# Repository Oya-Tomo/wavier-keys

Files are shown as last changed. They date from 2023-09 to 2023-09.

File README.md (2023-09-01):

# Wavier Keys Firmware and Circuit

## tech

tech

## description

this repo contains the firmware program written in Rust with rp-2040 bsp and circuit file made with kicad.

test, test, ah... ah...
This message was written with Wavier Keys keyboard.

## author

Oya-Tomo

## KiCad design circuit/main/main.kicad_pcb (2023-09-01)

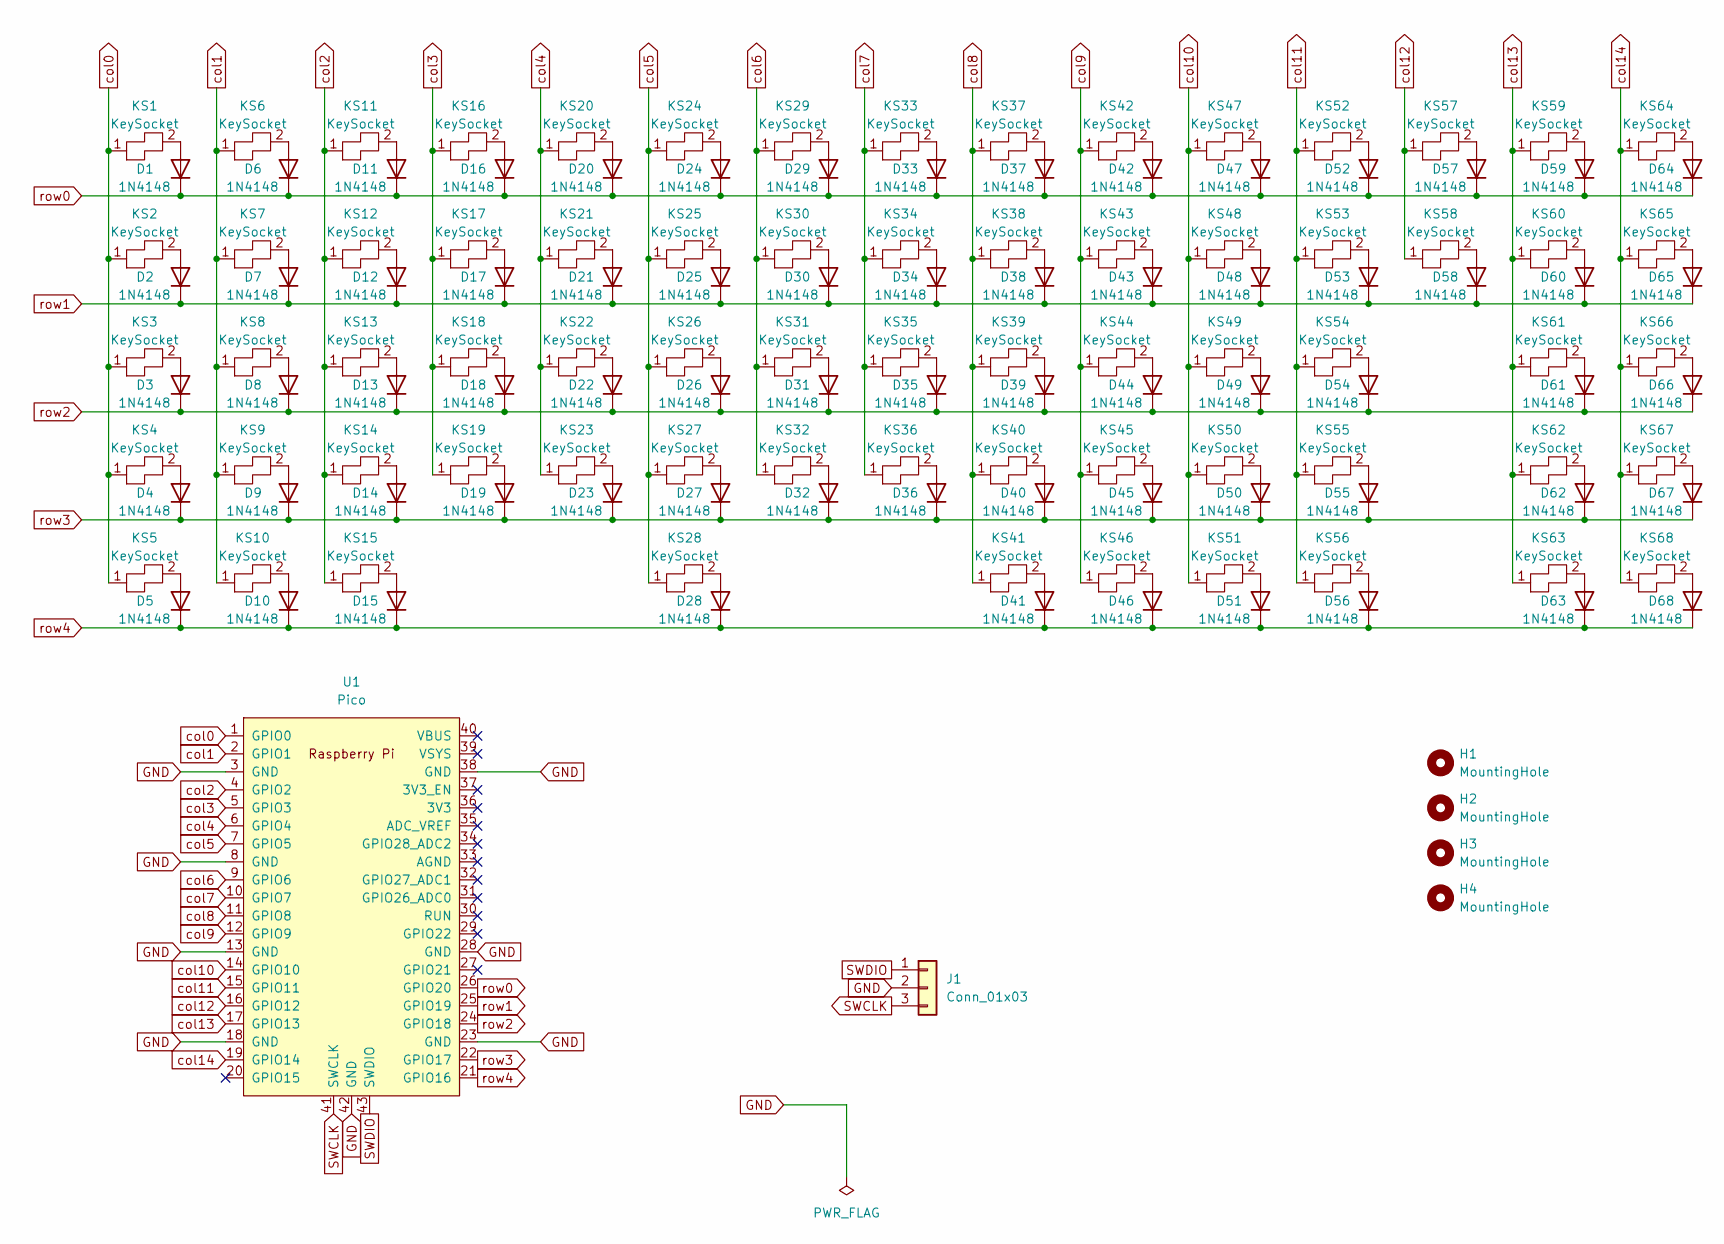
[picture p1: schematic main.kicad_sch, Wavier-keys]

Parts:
D1, D2, D3, D4, D5, D6, D7, D8, D9, D10, D11, D12, D13, D14, D15, D16, D17, D18, D19, D20, D21, D22, D23, D24, D25, D26, D27, D28, D29, D30, D31, D32, D33, D34, D35, D36, D37, D38, D39, D40, D41, D42, D43, D44, D45, D46, D47, D48, D49, D50, D51, D52, D53, D54, D55, D56, D57, D58, D59, D60, D61, D62, D63, D64, D65, D66, D67, D68: 1N4148; D_DO-35_SOD27_P7.62mm_Horizontal
H1, H2, H3, H4: MountingHole; MountingHole_2.5mm
J1: Conn_01x03; PinHeader_1x03_P2.54mm_Horizontal
KS1, KS6, KS7, KS8, KS9, KS11, KS12, KS13, KS14, KS16, KS17, KS18, KS19, KS20, KS21, KS22, KS23, KS24, KS25, KS26, KS27, KS29, KS30, KS31, KS32, KS33, KS34, KS35, KS36, KS37, KS38, KS39, KS40, KS41, KS42, KS43, KS44, KS45, KS46, KS47, KS48, KS49, KS50, KS51, KS52, KS53, KS54, KS56, KS57, KS58, KS59, KS62, KS63, KS65, KS66, KS67, KS68: KeySocket; SW_Hotswap_Kailh_MX_1.00u
KS2, KS60: KeySocket; SW_Hotswap_Kailh_MX_1.50u
KS3, KS55: KeySocket; SW_Hotswap_Kailh_MX_1.75u
KS4, KS61: KeySocket; SW_Hotswap_Kailh_MX_2.25u
KS5, KS10, KS15: KeySocket; SW_Hotswap_Kailh_MX_1.25u
KS28: KeySocket; SW_Hotswap_Kailh_MX_6.25u
KS64: KeySocket; SW_Hotswap_Kailh_MX_2.00u
U1: Pico; RPi_Pico_SMD_TH

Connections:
GND: J1.2, U1.3 (GND), U1.8 (GND), U1.13 (GND), U1.18 (GND), U1.23 (GND), U1.28 (GND), U1.38 (GND), U1.42 (GND)
unnamed: D1.2 (A), KS1.2
unnamed: D2.2 (A), KS2.2
unnamed: D3.2 (A), KS3.2
unnamed: D4.2 (A), KS4.2
unnamed: D5.2 (A), KS5.2
unnamed: D6.2 (A), KS6.2
unnamed: D7.2 (A), KS7.2
unnamed: D8.2 (A), KS8.2
unnamed: D9.2 (A), KS9.2
unnamed: D10.2 (A), KS10.2
unnamed: D11.2 (A), KS11.2
unnamed: D12.2 (A), KS12.2
unnamed: D13.2 (A), KS13.2
unnamed: D14.2 (A), KS14.2
unnamed: D15.2 (A), KS15.2
unnamed: D16.2 (A), KS16.2
unnamed: D17.2 (A), KS17.2
unnamed: D18.2 (A), KS18.2
unnamed: D19.2 (A), KS19.2
unnamed: D20.2 (A), KS20.2
unnamed: D21.2 (A), KS21.2
unnamed: D22.2 (A), KS22.2
unnamed: D23.2 (A), KS23.2
unnamed: D24.2 (A), KS24.2
unnamed: D25.2 (A), KS25.2
unnamed: D26.2 (A), KS26.2
unnamed: D27.2 (A), KS27.2
unnamed: D28.2 (A), KS28.2
unnamed: D29.2 (A), KS29.2
unnamed: D30.2 (A), KS30.2
unnamed: D31.2 (A), KS31.2
unnamed: D32.2 (A), KS32.2
unnamed: D33.2 (A), KS33.2
unnamed: D34.2 (A), KS34.2
unnamed: D35.2 (A), KS35.2
unnamed: D36.2 (A), KS36.2
unnamed: D37.2 (A), KS37.2
unnamed: D38.2 (A), KS38.2
unnamed: D39.2 (A), KS39.2
unnamed 40: D40.2 (A), KS40.2; also elsewhere on the board
unnamed: D41.2 (A), KS41.2
unnamed 42: D42.2 (A), KS42.2; also elsewhere on the board
unnamed: D43.2 (A), KS43.2
unnamed: D44.2 (A), KS44.2
unnamed: D45.2 (A), KS45.2
unnamed: D46.2 (A), KS46.2
unnamed: D47.2 (A), KS47.2
unnamed: D48.2 (A), KS48.2
unnamed: D49.2 (A), KS49.2
unnamed: D50.2 (A), KS50.2
unnamed: D51.2 (A), KS51.2
unnamed: D52.2 (A), KS52.2
unnamed: D53.2 (A), KS53.2
unnamed: D54.2 (A), KS54.2
unnamed: D55.2 (A), KS55.2
unnamed: D56.2 (A), KS56.2
unnamed: D57.2 (A), KS57.2
unnamed: D58.2 (A), KS58.2
unnamed: D59.2 (A), KS59.2
unnamed: D60.2 (A), KS60.2
unnamed: D61.2 (A), KS61.2
unnamed: D62.2 (A), KS62.2
unnamed: D63.2 (A), KS63.2
unnamed: D64.2 (A), KS64.2
unnamed: D65.2 (A), KS65.2
unnamed: D66.2 (A), KS66.2
unnamed: D67.2 (A), KS67.2
unnamed: D68.2 (A), KS68.2
SWCLK: J1.3, U1.41 (SWCLK)
SWDIO: J1.1, U1.43 (SWDIO)
col0: KS1.1, KS2.1, KS3.1, KS4.1, KS5.1, U1.1 (GPIO0)
col1: KS6.1, KS7.1, KS8.1, KS9.1, KS10.1, U1.2 (GPIO1)
col2: KS11.1, KS12.1, KS13.1, KS14.1, KS15.1, U1.4 (GPIO2)
col3: KS16.1, KS17.1, KS18.1, KS19.1, U1.5 (GPIO3)
col4: KS20.1, KS21.1, KS22.1, KS23.1, U1.6 (GPIO4)
col5: KS24.1, KS25.1, KS26.1, KS27.1, KS28.1, U1.7 (GPIO5)
col6: KS29.1, KS30.1, KS31.1, KS32.1, U1.9 (GPIO6)
col7: KS33.1, KS34.1, KS35.1, KS36.1, U1.10 (GPIO7)
col8: KS37.1, KS38.1, KS39.1, KS40.1, KS41.1, U1.11 (GPIO8); also elsewhere on the board
col9: KS42.1, KS43.1, KS44.1, KS45.1, KS46.1, U1.12 (GPIO9); also elsewhere on the board
col10: KS47.1, KS48.1, KS49.1, KS50.1, KS51.1, U1.14 (GPIO10)
col11: KS52.1, KS53.1, KS54.1, KS55.1, KS56.1, U1.15 (GPIO11)
col12: KS57.1, KS58.1, U1.16 (GPIO12)
col13: KS59.1, KS60.1, KS61.1, KS62.1, KS63.1, U1.17 (GPIO13)
col14: KS64.1, KS65.1, KS66.1, KS67.1, KS68.1, U1.19 (GPIO14)
row0: D1.1 (K), D6.1 (K), D11.1 (K), D16.1 (K), D20.1 (K), D24.1 (K), D29.1 (K), D33.1 (K), D37.1 (K), D42.1 (K), D47.1 (K), D52.1 (K), D57.1 (K), D59.1 (K), D64.1 (K), U1.26 (GPIO20)
row1: D2.1 (K), D7.1 (K), D12.1 (K), D17.1 (K), D21.1 (K), D25.1 (K), D30.1 (K), D34.1 (K), D38.1 (K), D43.1 (K), D48.1 (K), D53.1 (K), D58.1 (K), D60.1 (K), D65.1 (K), U1.25 (GPIO19)
row2: D3.1 (K), D8.1 (K), D13.1 (K), D18.1 (K), D22.1 (K), D26.1 (K), D31.1 (K), D35.1 (K), D39.1 (K), D44.1 (K), D49.1 (K), D54.1 (K), D61.1 (K), D66.1 (K), U1.24 (GPIO18)
row3: D4.1 (K), D9.1 (K), D14.1 (K), D19.1 (K), D23.1 (K), D27.1 (K), D32.1 (K), D36.1 (K), D40.1 (K), D45.1 (K), D50.1 (K), D55.1 (K), D62.1 (K), D67.1 (K), U1.22 (GPIO17)
row4: D5.1 (K), D10.1 (K), D15.1 (K), D28.1 (K), D41.1 (K), D46.1 (K), D51.1 (K), D56.1 (K), D63.1 (K), D68.1 (K), U1.21 (GPIO16)

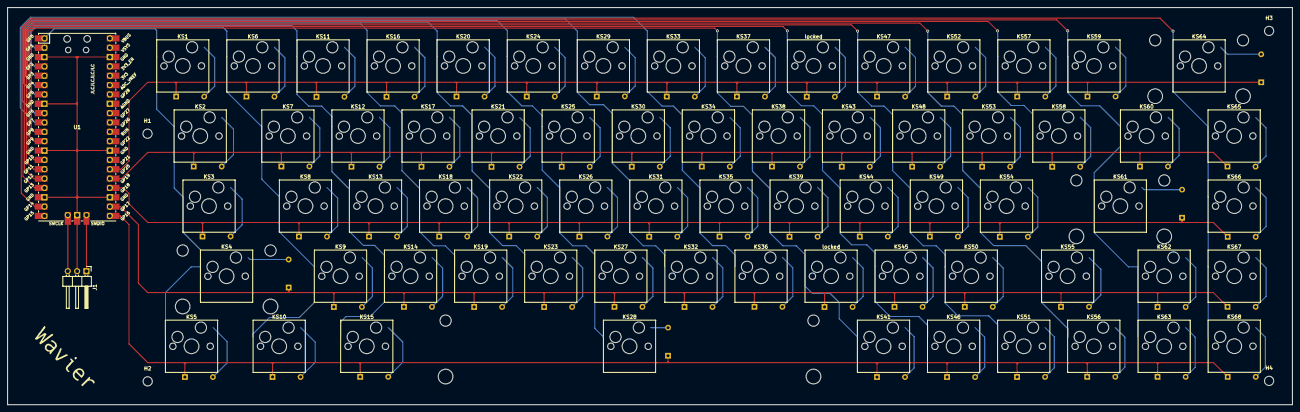
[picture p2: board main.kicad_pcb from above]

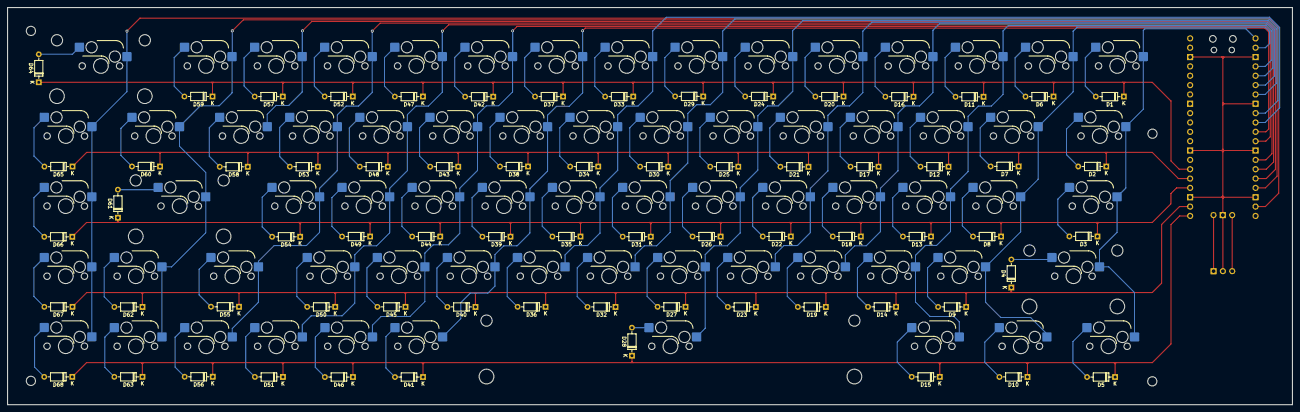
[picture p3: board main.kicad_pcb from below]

Board: 2 copper layers, 349.2 x 108.0 mm, 142 parts (68 on the bottom side), 91 nets.

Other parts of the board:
locked: KeySocket; SW_Hotswap_Kailh_MX_1.00u
locked#2: locked; SW_Hotswap_Kailh_MX_1.00u

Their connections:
unnamed 40: locked#2.2; also elsewhere on the board
unnamed 42: locked.2; also elsewhere on the board
col8: locked#2.1; also elsewhere on the board
col9: locked.1; also elsewhere on the board

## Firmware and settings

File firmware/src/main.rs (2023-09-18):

#![no_main]
#![no_std]

use core::{convert::Infallible, u8};

use cortex_m::{asm, prelude::*};
use cortex_m_rt::entry;

use defmt;
use defmt_rtt as _;
use embedded_hal::digital::v2::{InputPin, OutputPin};
use fugit::ExtU32;
use keycodes::{KeyCodes, ModifierMasks};
use layout::{
    FN_KEY_POS, KEY_LAYOUT, KEY_LAYOUT_WITH_FN, LEFT_ALT, LEFT_BUTTON, LEFT_CTRL, LEFT_GUI,
    LEFT_SHIFT, MODE_KEY_POS, MOVE_DOWN, MOVE_LEFT, MOVE_RIGHT, MOVE_UP, RIGHT_ALT, RIGHT_BUTTON,
    RIGHT_CTRL, RIGHT_GUI, RIGHT_SHIFT,
};
use panic_probe as _;

use rp_pico::{self, hal::usb::UsbBus};
use usb_device::{
    class_prelude::UsbBusAllocator,
    prelude::{UsbDeviceBuilder, UsbVidPid},
};
use usbd_hid::{
    descriptor::{KeyboardReport, MouseReport, SerializedDescriptor},
    hid_class::{
        HIDClass, HidClassSettings, HidCountryCode, HidProtocol, HidSubClass, ProtocolModeConfig,
    },
};

mod keycodes;
mod layout;

#[defmt::panic_handler]
fn panic() -> ! {
    cortex_m::asm::udf();
}

pub fn exit() -> ! {
    loop {
        cortex_m::asm::bkpt();
    }
}

pub type Column<'a> = &'a dyn InputPin<Error = Infallible>;
pub type Row<'a> = &'a mut dyn OutputPin<Error = Infallible>;
pub type MatrixState = [[bool; 15]; 5];

#[derive(PartialEq)]
enum KeyboardMode {
    Normal,
    Saving,
}

const KEYBOARD_POLL_MS: u32 = 10;
const KEYBOARD_POLL_MS_SAVING: u32 = 20;
const IDLE_WAIT_SEC: u32 = 5;

#[entry]
fn main() -> ! {
    let mut dp = rp_pico::hal::pac::Peripherals::take().unwrap();
    let mut watchdog = rp_pico::hal::Watchdog::new(dp.WATCHDOG);
    let clocks = rp_pico::hal::clocks::init_clocks_and_plls(
        rp_pico::XOSC_CRYSTAL_FREQ,
        dp.XOSC,
        dp.CLOCKS,
        dp.PLL_SYS,
        dp.PLL_USB,
        &mut dp.RESETS,
        &mut watchdog,
    )
    .ok()
    .unwrap();
    let timer = rp_pico::hal::Timer::new(dp.TIMER, &mut dp.RESETS);

    let bus = UsbBus::new(
        dp.USBCTRL_REGS,
        dp.USBCTRL_DPRAM,
        clocks.usb_clock,
        true,
        &mut dp.RESETS,
    );
    let bus_allocator = UsbBusAllocator::new(bus);

    let mut kb_hid = HIDClass::new_with_settings(
        &bus_allocator,
        KeyboardReport::desc(),
        KEYBOARD_POLL_MS as u8,
        HidClassSettings {
            subclass: HidSubClass::NoSubClass,
            protocol: HidProtocol::Keyboard,
            config: ProtocolModeConfig::ForceReport,
            locale: HidCountryCode::NotSupported,
        },
    );

    let mut ms_hid = HIDClass::new_with_settings(
        &bus_allocator,
        MouseReport::desc(),
        10,
        HidClassSettings {
            subclass: HidSubClass::NoSubClass,
            protocol: HidProtocol::Mouse,
            config: ProtocolModeConfig::ForceReport,
            locale: HidCountryCode::NotSupported,
        },
    );

    let mut usb_dev = UsbDeviceBuilder::new(&bus_allocator, UsbVidPid(0x2718, 0x2818))
        .manufacturer("Oya-Tomo")
        .product("Wavier-Keys")
        .serial_number("2023.9.13.18.57")
        .build();

    let sio = rp_pico::hal::Sio::new(dp.SIO);
    let pins = rp_pico::Pins::new(dp.IO_BANK0, dp.PADS_BANK0, sio.gpio_bank0, &mut dp.RESETS);

    let col0 = pins.gpio0.into_pull_up_input();
    let col1 = pins.gpio1.into_pull_up_input();
    let col2 = pins.gpio2.into_pull_up_input();
    let col3 = pins.gpio3.into_pull_up_input();
    let col4 = pins.gpio4.into_pull_up_input();
    let col5 = pins.gpio5.into_pull_up_input();
    let col6 = pins.gpio6.into_pull_up_input();
    let col7 = pins.gpio7.into_pull_up_input();
    let col8 = pins.gpio8.into_pull_up_input();
    let col9 = pins.gpio9.into_pull_up_input();
    let col10 = pins.gpio10.into_pull_up_input();
    let col11 = pins.gpio11.into_pull_up_input();
    let col12 = pins.gpio12.into_pull_up_input();
    let col13 = pins.gpio13.into_pull_up_input();
    let col14 = pins.gpio14.into_pull_up_input();

    let mut row0 = pins.gpio20.into_push_pull_output();
    let mut row1 = pins.gpio19.into_push_pull_output();
    let mut row2 = pins.gpio18.into_push_pull_output();
    let mut row3 = pins.gpio17.into_push_pull_output();
    let mut row4 = pins.gpio16.into_push_pull_output();

    let mut led = pins.led.into_push_pull_output();

    let cols: &[Column] = &[
        &col0, &col1, &col2, &col3, &col4, &col5, &col6, &col7, &col8, &col9, &col10, &col11,
        &col12, &col13, &col14,
    ];
    let rows: &mut [Row] = &mut [&mut row0, &mut row1, &mut row2, &mut row3, &mut row4];

    let mut countdown = timer.count_down();
    countdown.start(KEYBOARD_POLL_MS.millis());

    let mut keyboard_mode = KeyboardMode::Normal;
    let mut last_input_frame = 0;
    let mut frame: u32 = 0;

    loop {
        usb_dev.poll(&mut [&mut kb_hid, &mut ms_hid]);
        if countdown.wait().is_ok() {
            if last_input_frame == frame {
                keyboard_mode = KeyboardMode::Saving;
            }

            if keyboard_mode == KeyboardMode::Normal
                || frame % (KEYBOARD_POLL_MS_SAVING / KEYBOARD_POLL_MS) == 0
            {
                let (mtx, empty) = scan_key_switch(cols, rows);
                if empty {
                    kb_hid
                        .push_input(&KeyboardReport {
                            modifier: 0,
                            reserved: 0,
                            leds: 0,
                            keycodes: [0, 0, 0, 0, 0, 0],
                        })
                        .ok();
                    ms_hid
                        .push_input(&MouseReport {
                            buttons: 0,
                            x: 0,
                            y: 0,
                            wheel: 0,
                            pan: 0,
                        })
                        .ok();
                } else {
                    if mode_switch(&mtx) {
                        let report = build_keyboard_report(mtx);
                        kb_hid.push_input(&report).ok();
                    } else {
                        let report = build_mouse_report(mtx);
                        ms_hid.push_input(&report).ok();
                    }
                    last_input_frame = frame;
                    keyboard_mode = KeyboardMode::Normal;
                }
            } else {
                kb_hid
                    .push_input(&KeyboardReport {
                        modifier: 0,
                        reserved: 0,
                        leds: 0,
                        keycodes: [0, 0, 0, 0, 0, 0],
                    })
                    .ok();
                ms_hid
                    .push_input(&MouseReport {
                        buttons: 0,
                        x: 0,
                        y: 0,
                        wheel: 0,
                        pan: 0,
                    })
                    .ok();
            }

            frame = (frame + 1) % (1000 / KEYBOARD_POLL_MS * IDLE_WAIT_SEC);
        }
        kb_hid.pull_raw_output(&mut [0; 64]).ok();
        if keyboard_mode == KeyboardMode::Normal {
            led.set_high().unwrap();
        } else {
            led.set_low().unwrap();
        }
    }
}

fn mode_switch(state: &MatrixState) -> bool {
    // true : keyboard, false : mouse
    return !state[MODE_KEY_POS[0]][MODE_KEY_POS[1]];
}

fn scan_key_switch(cols: &[Column], rows: &mut [Row]) -> (MatrixState, bool) {
    let mut empty = true;
    let mut state: MatrixState = [[false; 15]; 5];
    for row in 0..rows.len() {
        rows[row].set_low().unwrap();
        asm::delay(10);
        for col in 0..cols.len() {
            state[row][col] = cols[col].is_low().unwrap();
            if state[row][col] {
                empty = false;
            }
        }
        rows[row].set_high().unwrap();
        asm::delay(10);
    }
    return (state, empty);
}

fn build_keyboard_report(state: MatrixState) -> KeyboardReport {
    let mut modif = 0;
    let mut key_codes: [u8; 6] = [0; 6];
    let mut count = 0;

    if state[FN_KEY_POS[0]][FN_KEY_POS[1]] {
        for row in 0..state.len() {
            for col in 0..state[0].len() {
                if state[row][col] && KEY_LAYOUT_WITH_FN[row][col] != KeyCodes::Reserved {
                    if count < 6 {
                        key_codes[count] = KEY_LAYOUT_WITH_FN[row][col] as u8;
                        count += 1;
                    } else {
                        key_codes = [KeyCodes::ErrOvf as u8; 6];
                        break;
                    }
                }
            }
        }
    } else {
        for row in 0..state.len() {
            for col in 0..state[0].len() {
                if state[row][col] && KEY_LAYOUT[row][col] != KeyCodes::Reserved {
                    if count < 6 {
                        key_codes[count] = KEY_LAYOUT[row][col] as u8;
                        count += 1;
                    } else {
                        key_codes = [KeyCodes::ErrOvf as u8; 6];
                        break;
                    }
                }
            }
        }
    }

    if state[LEFT_CTRL[0]][LEFT_CTRL[1]] {
        modif |= ModifierMasks::LeftCtrl as u8;
    }
    if state[LEFT_SHIFT[0]][LEFT_SHIFT[1]] {
        modif |= ModifierMasks::LeftShift as u8;
    }
    if state[LEFT_ALT[0]][LEFT_ALT[1]] {
        modif |= ModifierMasks::LeftAlt as u8;
    }
    if state[LEFT_GUI[0]][LEFT_GUI[1]] {
        modif |= ModifierMasks::LeftGui as u8;
    }

    if state[RIGHT_CTRL[0]][RIGHT_CTRL[1]] {
        modif |= ModifierMasks::RightCtrl as u8;
    }
    if state[RIGHT_SHIFT[0]][RIGHT_SHIFT[1]] {
        modif |= ModifierMasks::RightShift as u8;
    }
    if state[RIGHT_ALT[0]][RIGHT_ALT[1]] {
        modif |= ModifierMasks::RightAlt as u8;
    }
    if state[RIGHT_GUI[0]][RIGHT_GUI[1]] {
        modif |= ModifierMasks::RightGui as u8;
    }

    KeyboardReport {
        modifier: modif,
        reserved: 0,
        leds: 0,
        keycodes: key_codes,
    }
}

fn build_mouse_report(state: MatrixState) -> MouseReport {
    let mut report = MouseReport {
        buttons: 0,
        x: 0,
        y: 0,
        wheel: 0,
        pan: 0,
    };

    if state[LEFT_BUTTON[0]][LEFT_BUTTON[1]] {
        report.buttons |= 1 << 0;
    }
    if state[RIGHT_BUTTON[0]][RIGHT_BUTTON[1]] {
        report.buttons |= 1 << 1;
    }

    if state[MOVE_LEFT[0]][MOVE_LEFT[1]] {
        report.x -= 3;
    }
    if state[MOVE_RIGHT[0]][MOVE_RIGHT[1]] {
        report.x += 3;
    }
    if state[MOVE_UP[0]][MOVE_UP[1]] {
        report.y -= 3;
    }
    if state[MOVE_DOWN[0]][MOVE_DOWN[1]] {
        report.y += 3;
    }

    return report;
}

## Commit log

2023-09-01 first commit & completed
    [main.kicad_pcb, main.kicad_sch, top.kicad_pcb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]
2023-09-18 fixed: frame rate && saving feature -beta
    [main.rs]
